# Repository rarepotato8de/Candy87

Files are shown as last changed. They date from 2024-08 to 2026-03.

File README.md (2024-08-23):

# Candy87: A universal TKL PCB 💙
The Candy87 Hotswap PCB was exclusively made for and in cooperation with [Candykeys](https://candykeys.com/) and designed to fit the Geonworks F1-8X V2 and other TKL keyboards. It supports many layout options and has awesome features!

Candy87_Top_View

## Features
- H87/H88 Compatible
- ISO and/or ANSI Support (See supported layout notes!)
- Standard and Tsangan Bottom Row
- O-Ring Cutouts
- Breakable USB-C Port (Daughterboard can be used with JST)
- Indicator LED's for Caps- and Scrolllock
- RP2040 Chip
- Broken-out GPIO Pins
- QMK/VIAL Support

## Firmware & Flashing
[QMK](https://github.com/qmk/qmk_firmware/tree/master/keyboards/candykeys/candy87) and [VIAL](https://github.com/vial-kb/vial-qmk/tree/vial/keyboards/candykeys/candy87) firmwares are available in their repositories. The compiled VIAL firmware can be found [here](https://github.com/rarepotato8de/Candy87/blob/main/candy87_vial.uf2).

To flash the PCB the first time, you just have to plug it into your computer via. USB-C or Daughterboard and then in your explorer there should appear a new drive medium called "RPI-RP2" or similar. Just drag&drop the .UF2 file onto the drive and the window should automatically close and the PCB will now be flashed and functional.
For flashing it another time, plug in the PCB and hold down the "BOOT" button on the backside of the PCB, press the "RESET" button two times and then release the "BOOT" button again. After that the "RPI-RP2" medium should appear.

## Supported layouts


> [!IMPORTANT]
> Due to hotswap sockets interfering with both ANSI and ISO support, only one of these options can be used at a time.
> Candykeys version comes with ISO by default, but by resoldering two hotswap sockets it can be ANSI. See picture below (it's resoldered to ANSI)



## Breakable USB-C Port
> [!CAUTION]
> Be careful when removing/ breaking-off the USB-C port. It should be done with caution and pliers.
> It's recommended to place the PCB on a flat surface (e.g. a table), with the USB-C port "hanging" off the side and then wiggling up and down with your pliers until it breaks off.

> [!CAUTION]
> Please do this step outside or somewhere but inside.
> You should wear glasses and a mask to prevent any health risks from the FR4 dust.

https://github.com/user-attachments/assets/5fa9985e-4570-457c-9966-bd2f55c6e134

## Open Source
This project will be open sourced in the future! Stay tuned..

## Start of this project
The project came up in the beginning of 2024 when Geonworks announced another groupbuy for his popular keyboard, the F1-8X V2. For european fellas, Candykeys wanted to offer an ISO hotswap PCB. So we talked, made plans and finally built this awesome project together!
There was a lot demand for it, people were interested and excited for it and me too! So I'm super honored to be part of this and will look forward for further projects. The Candy87 is the first project I've ever done in cooperation with a company, so I gave my best at all time. Even though we have had an issue with our first prototype, because of switch interference, the second version not only fixed this issue, but was improved even more. From the beginning it was made to be open source, because both Candykeys and I are a fan of this concept.

Big shoutout and thanks to @zitres 🍋🍋 and @candykeys 💙

## Questions?
Feel free to message me!

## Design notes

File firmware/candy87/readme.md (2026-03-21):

# Candy87

Candy87

The Candy87 Hotswap PCB is a universal TKL PCB by Candykeys.
It supports ISO Hotswap by default (ANSI possible with desolering two hotswap sockets) and many layout options. 
It was mainly made for the F1-8X V2, but fits similar keyboards as well.

* Keyboard Maintainer: [RarePotato8DE](https://github.com/rarepotato8de)
* Hardware Supported: Candy87 PCB for F1-8X V2 and similar
* Hardware Availability: [Buy on Candykeys](https://candykeys.com/product/candy87-hotswap-pcb-iso)

Make example for this keyboard (after setting up your build environment):

    make candykeys/candy87:default

Flashing example for this keyboard:

    make candykeys/candy87:default:flash

See the [build environment setup](https://docs.qmk.fm/#/getting_started_build_tools) and the [make instructions](https://docs.qmk.fm/#/getting_started_make_guide) for more information. Brand new to QMK? Start with our [Complete Newbs Guide](https://docs.qmk.fm/#/newbs).

## Bootloader

Enter the bootloader in 3 ways:

* **Bootmagic reset**: Hold down the key at (0,0) in the matrix (usually the top left key or Escape) and plug in the keyboard
* **Physical reset button**: Hold down the "BOOT" button on the back and double press "RESET". Release "BOOT" after
* **Keycode in layout**: Press the key mapped to `QK_BOOT` if it is available

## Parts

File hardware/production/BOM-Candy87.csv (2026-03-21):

Comment | Designator | Footprint | LCSC
100n | C10,C16,C2,C3,C4,C5,C6,C7,C8,C9 | C_0603_1608Metric | C14663
100nF | C17,C18,C19 | C_0402_1005Metric | C1525
1u | C12,C13 | C_0603_1608Metric | C15849
ai03_ud | J1 | JST-SR-4 | C160404
22p | C1,C11 | C_0603_1608Metric | C1653
USB_C_Receptacle_USB2.0 | J2 | USB_C_Receptacle_HRO_TYPE-C-31-M-12 | C165948
RP2040 | U1 | RP2040-QFN-56 | C2040
1k | R3,R7 | R_0603_1608Metric | C21190
470 | R8 | R_0603_1608Metric | C23179
5.1k | R4,R5 | R_0603_1608Metric | C23186
22 | R1,R2 | R_0603_1608Metric | C23345
RESET | RESET1,USB_BOOT1 | SW_SPST_TL3342 | C318884
SK6812MINI-E | LED1,LED2 | LED_6028R | C5149201
1u | MX1,MX10,MX100,MX101,MX102,MX103,MX104,MX11,MX12,MX13,MX14,MX15,MX16,MX17,MX18,MX19,MX2,MX20,MX21,MX22,MX23,MX24,MX25,MX26,MX27,MX28,MX29,MX3,MX30,MX31,MX32,MX33,MX34,MX35,MX36,MX37,MX38,MX39,MX4,MX40,MX41,MX42,MX43,MX44,MX45,MX46,MX47,MX48,MX49,MX5,MX50,MX52,MX53,MX54,MX55,MX56,MX57,MX58,MX59,MX6,MX60,MX61,MX62,MX63,MX64,MX65,MX66,MX67,MX68,MX7,MX70,MX71,MX72,MX73,MX74,MX75,MX76,MX77,MX78,MX79,MX8,MX80,MX81,MX82,MX83,MX84,MX85,MX86,MX87,MX88,MX89,MX9,MX90,MX91,MX92,MX93,MX94,MX95,MX96,MX97,MX98,MX99 | MXOnly-1U-Hotswap | C5156480
12MHz | Y1 | Crystal_SMD_3225-4Pin_3.2x2.5mm | C518158
USBLC6-2SC6 | U4 | SOT-23-6 | C558442
22u | C14,C15 | C_0603_1608Metric | C59461
AMS1117-3.3 | U2 | SOT-223-3_TabPin2 | C6186
74AHCT1G125 | U5 | SOT-23-5 | C7484
1N4148 | D1,D10,D11,D12,D13,D14,D15,D16,D17,D18,D19,D2,D20,D21,D22,D23,D24,D25,D26,D27,D28,D29,D3,D30,D31,D32,D33,D34,D35,D36,D37,D38,D39,D4,D40,D41,D42,D43,D44,D45,D46,D47,D48,D49,D5,D50,D51,D52,D53,D54,D55,D56,D57,D58,D59,D6,D60,D61,D62,D63,D64,D65,D66,D67,D68,D69,D7,D70,D71,D72,D73,D74,D75,D76,D77,D78,D79,D8,D80,D81,D82,D83,D84,D85,D86,D87,D88,D89,D9,D90,D91 | D_SOD-123 | C81598
W25Q128JVS | U3 | SOIC-8_5.23x5.23mm_P1.27mm | C97521

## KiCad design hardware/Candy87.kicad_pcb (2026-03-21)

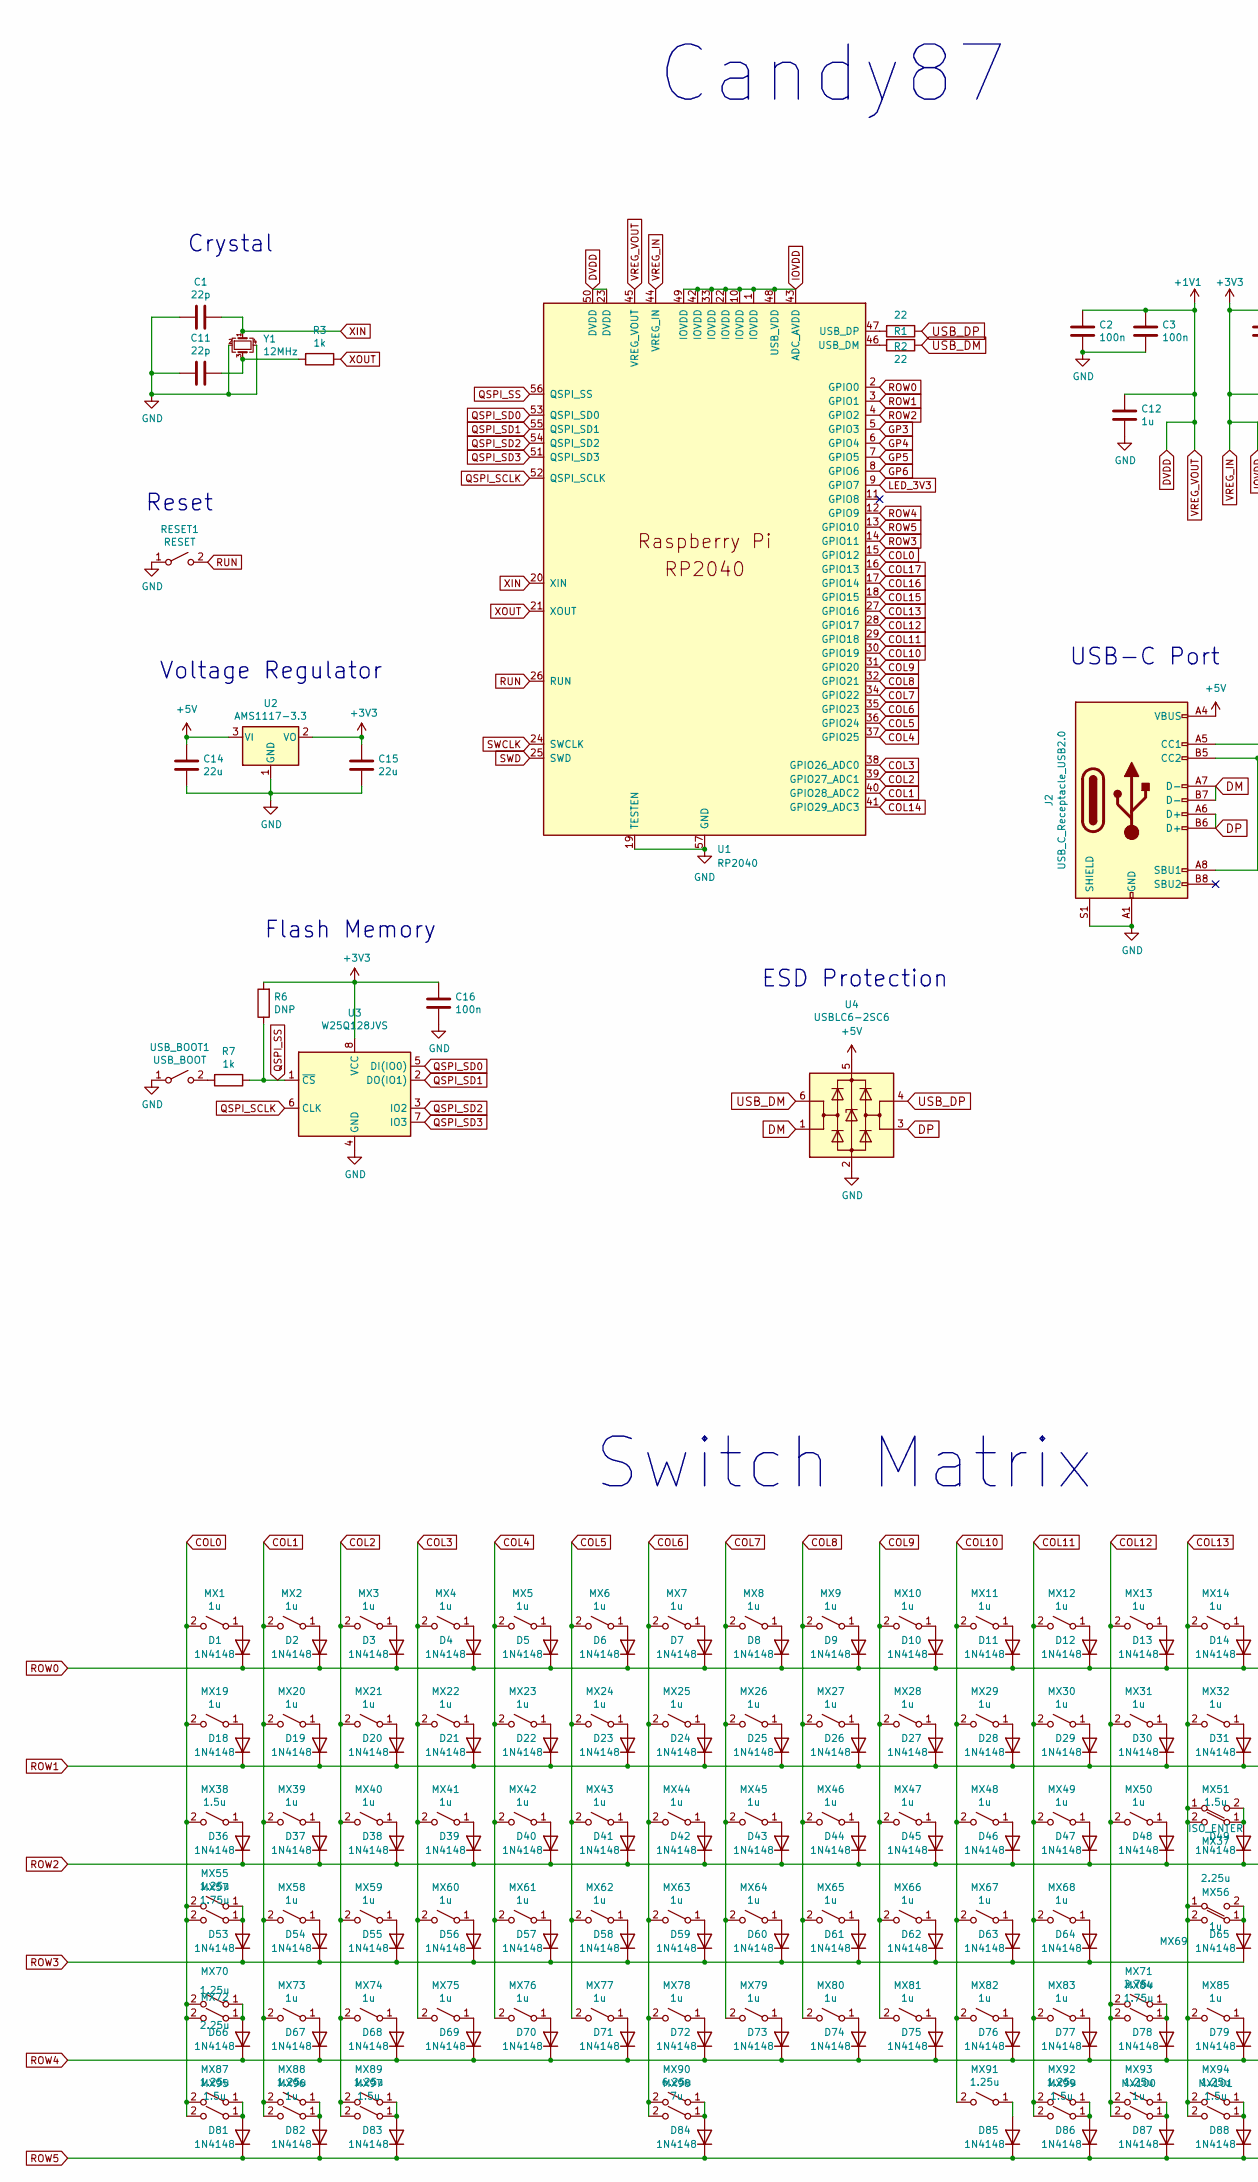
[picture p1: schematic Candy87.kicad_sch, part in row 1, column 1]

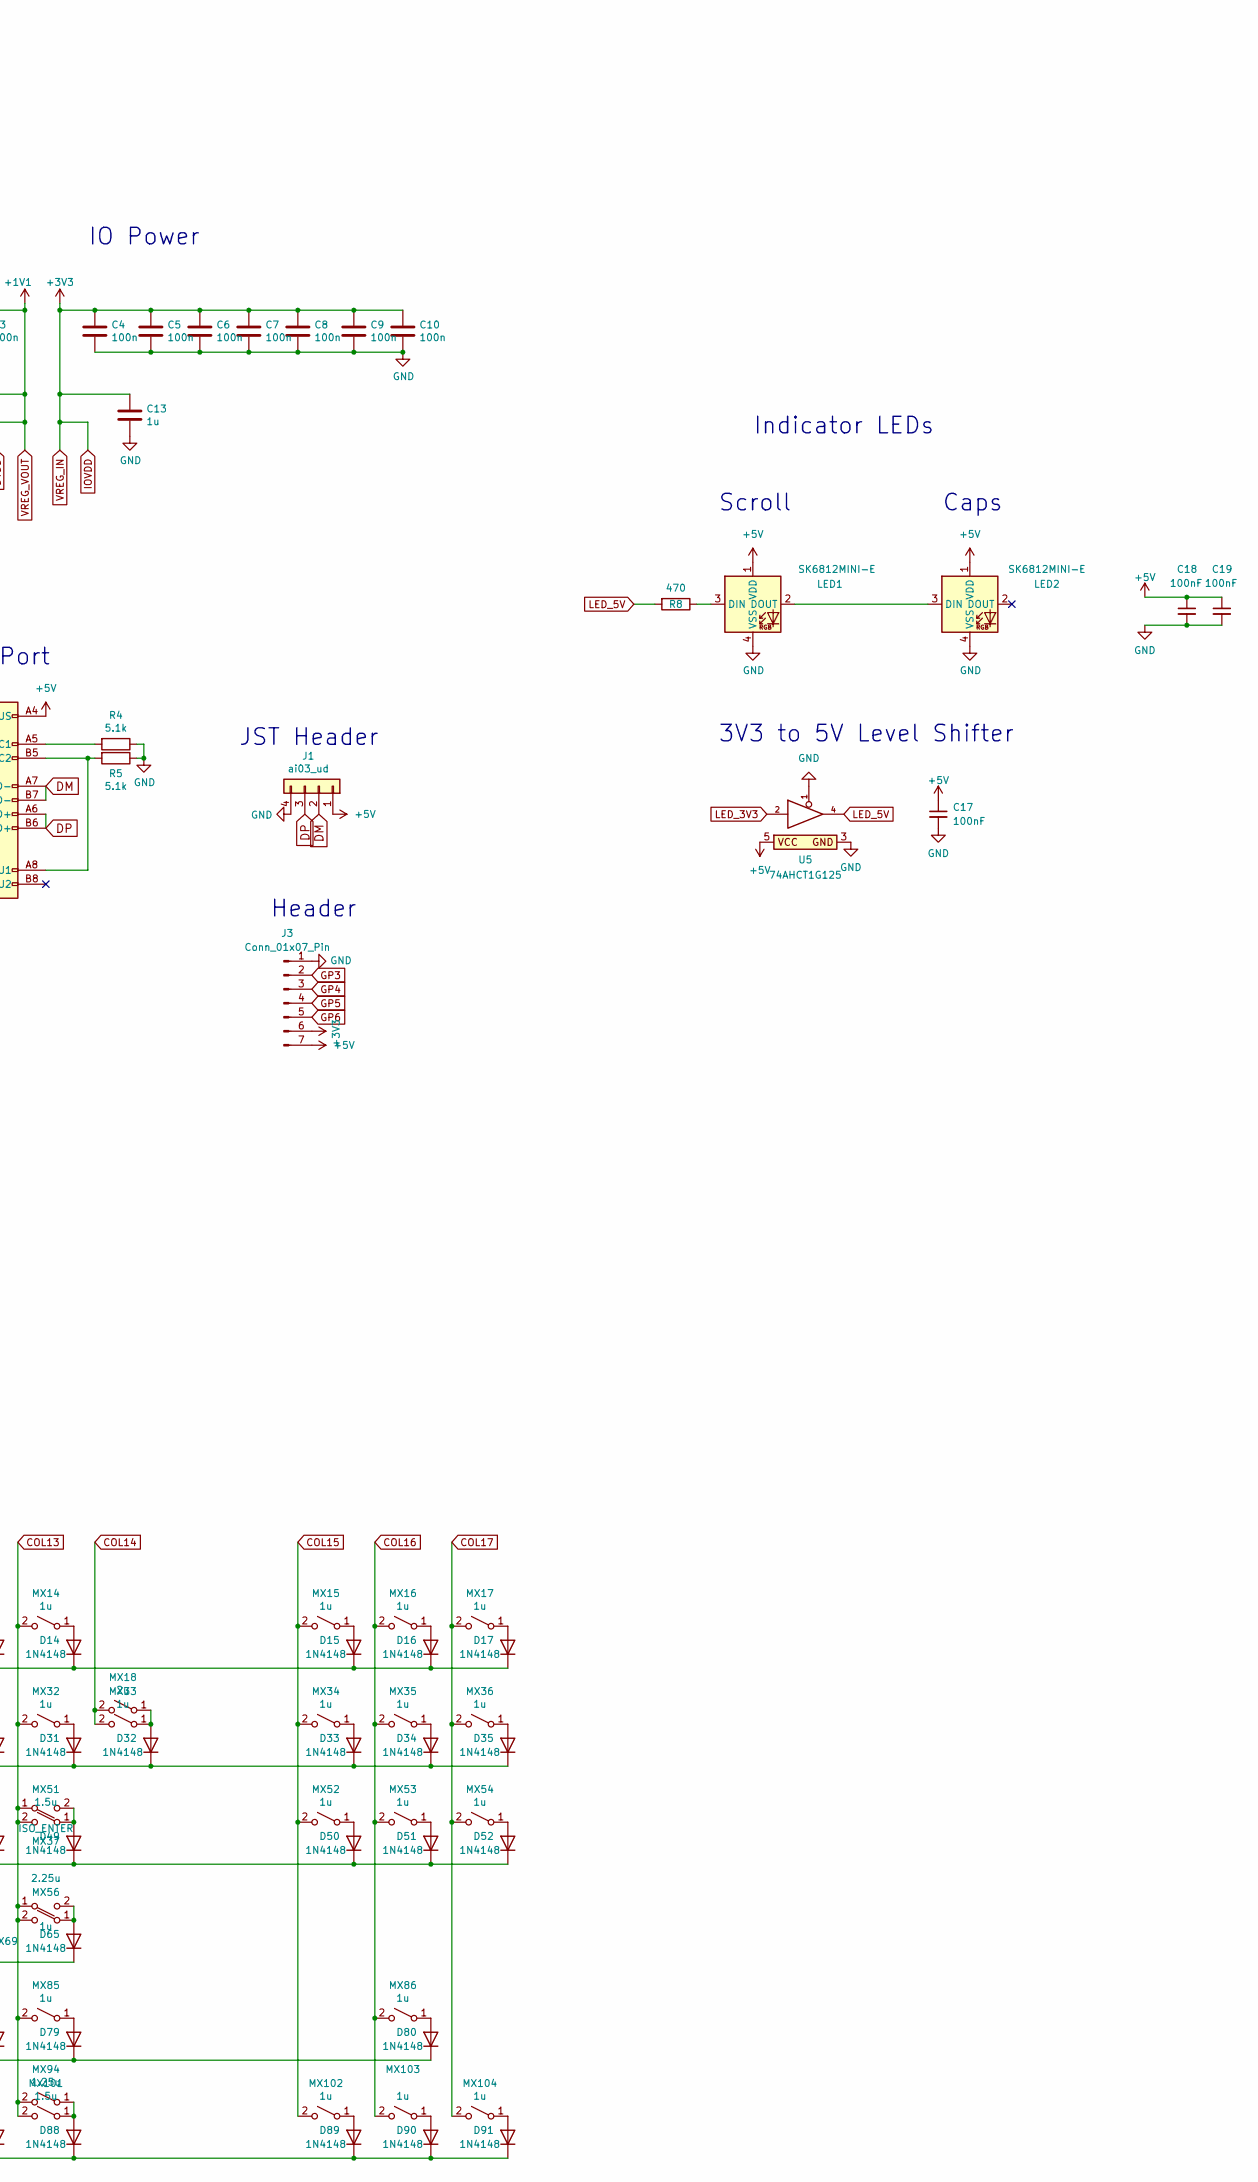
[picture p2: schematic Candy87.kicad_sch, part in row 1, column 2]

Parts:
C1, C11: 22p; C_0603_1608Metric; LCSC C1653
C2, C3, C4, C5, C6, C7, C8, C9, C10, C16: 100n; C_0603_1608Metric; LCSC C14663
C12, C13: 1u; C_0603_1608Metric; LCSC C15849
C14, C15: 22u; C_0603_1608Metric; LCSC C59461
C17, C18, C19: 100nF; C_0402_1005Metric; LCSC C1525
D1, D2, D3, D4, D5, D6, D7, D8, D9, D10, D11, D12, D13, D14, D15, D16, D17, D18, D19, D20, D21, D22, D23, D24, D25, D26, D27, D28, D29, D30, D31, D32, D33, D34, D35, D36, D37, D38, D39, D40, D41, D42, D43, D44, D45, D46, D47, D48, D49, D50, D51, D52, D53, D54, D55, D56, D57, D58, D59, D60, D61, D62, D63, D64, D65, D66, D67, D68, D69, D70, D71, D72, D73, D74, D75, D76, D77, D78, D79, D80, D81, D82, D83, D84, D85, D86, D87, D88, D89, D90, D91: 1N4148; D_SOD-123; LCSC Part # C81598
J1: ai03_ud; JST-SR-4; LCSC C160404
J2: USB_C_Receptacle_USB2.0; USB_C_Receptacle_HRO_TYPE-C-31-M-12; LCSC C165948
J3: Conn_01x07_Pin; PinSocket_1x07_P2.54mm_Vertical
LED1, LED2: SK6812MINI-E; LED_6028R; LCSC C5149201
MX1, MX2, MX3, MX4, MX5, MX6, MX7, MX8, MX9, MX10, MX11, MX12, MX13, MX14, MX15, MX16, MX17, MX19, MX20, MX21, MX22, MX23, MX24, MX25, MX26, MX27, MX28, MX29, MX30, MX31, MX32, MX33, MX34, MX35, MX36, MX39, MX40, MX41, MX42, MX43, MX44, MX45, MX46, MX47, MX48, MX49, MX50, MX52, MX53, MX54, MX56, MX58, MX59, MX60, MX61, MX62, MX63, MX64, MX65, MX66, MX67, MX68, MX73, MX74, MX75, MX76, MX77, MX78, MX79, MX80, MX81, MX82, MX83, MX85, MX86, MX96, MX100, MX102, MX103, MX104: 1u; MXOnly-1U-Hotswap; LCSC C5156480
MX18: 2u; MXOnly-2U-Hotswap; LCSC C5156480
MX37: ISO_ENTER; MXOnly-ISO-Hotswap-ReversedStabilizers; LCSC C5156480
MX38, MX95, MX97, MX99, MX101: 1.5u; MXOnly-1.5U-Hotswap; LCSC C5156480
MX51: 1.5u; MXOnly-1.5U-Hotswap
MX55, MX70, MX87, MX88, MX89, MX91, MX92, MX93, MX94: 1.25u; MXOnly-1.25U-Hotswap; LCSC C5156480
MX57, MX84: 1.75u; MXOnly-1.75U-Hotswap; LCSC C5156480
MX69: 2.25u; MXOnly-2.25U-Hotswap
MX71: 2.75u; MXOnly-2.75U-Hotswap; LCSC C5156480
MX72: 2.25u; MXOnly-2.25U-Hotswap; LCSC C5156480
MX90: 6.25u; MXOnly-6.25U-Hotswap-ReversedStabilizers; LCSC C5156480
MX98: 7u; MXOnly-7U-Hotswap; LCSC C5156480
R1, R2: 22; R_0603_1608Metric; LCSC C23345
R3, R7: 1k; R_0603_1608Metric; LCSC C21190
R4, R5: 5.1k; R_0603_1608Metric; LCSC C23186
R6: DNP; R_0603_1608Metric
R8: 470; R_0603_1608Metric; LCSC C23179
RESET1: RESET; SW_SPST_TL3342; LCSC C318884
U1: RP2040; RP2040-QFN-56; LCSC C2040
U2: AMS1117-3.3; SOT-223-3_TabPin2; LCSC C6186
U3: W25Q128JVS; SOIC-8_5.23x5.23mm_P1.27mm; LCSC C97521
U4: USBLC6-2SC6; SOT-23-6; LCSC C558442
U5: 74AHCT1G125; SOT-23-5; LCSC C7484
USB_BOOT1: USB_BOOT; SW_SPST_TL3342; LCSC C318884
Y1: 12MHz; Crystal_SMD_3225-4Pin_3.2x2.5mm; MPN Crystal MPN; LCSC C518158

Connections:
+5V: C14.1, C17.1, C18.1, C19.1, J1.1, J2.A4 (VBUS), J2.A9 (VBUS), J2.B4 (VBUS), J2.B9 (VBUS), J3.7, LED1.1 (VDD), LED2.1 (VDD), U2.3 (VI), U4.5 (VBUS), U5.5
COL0: MX1.2 (B), MX19.2 (B), MX38.2 (B), MX55.2 (B), MX57.2 (B), MX70.2 (B), MX72.2 (B), MX87.2 (B), MX95.2 (B), U1.15 (GPIO12)
COL1: MX2.2 (B), MX20.2 (B), MX39.2 (B), MX58.2 (B), MX73.2 (B), MX88.2 (B), MX96.2 (B), U1.40 (GPIO28_ADC2); also elsewhere on the board
COL2: MX3.2 (B), MX21.2 (B), MX40.2 (B), MX59.2 (B), MX74.2 (B), MX89.2 (B), MX97.2 (B), U1.39 (GPIO27_ADC1); also elsewhere on the board
COL3: MX4.2 (B), MX22.2 (B), MX41.2 (B), MX60.2 (B), MX75.2 (B), U1.38 (GPIO26_ADC0); also elsewhere on the board
COL4: MX5.2 (B), MX23.2 (B), MX42.2 (B), MX61.2 (B), MX76.2 (B), U1.37 (GPIO25); also elsewhere on the board
COL5: MX6.2 (B), MX24.2 (B), MX43.2 (B), MX62.2 (B), MX77.2 (B), U1.36 (GPIO24)
COL6: MX7.2 (B), MX25.2 (B), MX44.2 (B), MX63.2 (B), MX78.2 (B), MX90.2 (B), MX98.2 (B), U1.35 (GPIO23)
COL7: MX8.2 (B), MX26.2 (B), MX45.2 (B), MX64.2 (B), MX79.2 (B), U1.34 (GPIO22)
COL8: MX9.2 (B), MX27.2 (B), MX46.2 (B), MX65.2 (B), MX80.2 (B), U1.32 (GPIO21)
COL9: MX10.2 (B), MX28.2 (B), MX47.2 (B), MX66.2 (B), MX81.2 (B), U1.31 (GPIO20); also elsewhere on the board
COL10: MX11.2 (B), MX29.2 (B), MX48.2 (B), MX67.2 (B), MX82.2 (B), MX91.2 (B), U1.30 (GPIO19); also elsewhere on the board
COL11: MX12.2 (B), MX30.2 (B), MX49.2 (B), MX68.2 (B), MX83.2 (B), MX92.2 (B), MX99.2 (B), U1.29 (GPIO18); also elsewhere on the board
COL12: MX13.2 (B), MX31.2 (B), MX50.2 (B), MX71.2 (B), MX84.2 (B), MX93.2 (B), MX100.2 (B), U1.28 (GPIO17); also elsewhere on the board
COL13: MX14.2 (B), MX32.2 (B), MX37.1 (A), MX51.2 (B), MX56.1 (A), MX69.2 (B), MX85.2 (B), MX94.2 (B), MX101.2 (B), U1.27 (GPIO16)
COL14: MX18.2 (B), MX33.2 (B), U1.41 (GPIO29_ADC3)
COL15: MX15.2 (B), MX34.2 (B), MX52.2 (B), MX102.2 (B), U1.18 (GPIO15)
COL16: MX16.2 (B), MX35.2 (B), MX53.2 (B), MX86.2 (B), MX103.2 (B), U1.17 (GPIO14)
COL17: MX17.2 (B), MX36.2 (B), MX54.2 (B), MX104.2 (B), U1.16 (GPIO13)
DM: J1.2, J2.A7 (D-), J2.B7 (D-), U4.1 (I/O1)
DP: J1.3, J2.A6 (D+), J2.B6 (D+), U4.3 (I/O2)
DVDD: C2.1, C3.1, C12.1, U1.23 (DVDD), U1.45 (VREG_VOUT), U1.50 (DVDD)
GND: C1.2, C2.2, C3.2, C4.2, C5.2, C6.2, C7.2, C8.2, C9.2, C10.2, C11.2, C12.2, C13.2, C14.2, C15.2, C16.2, C17.2, C18.2, C19.2, J1.4, J2.A1 (GND), J2.A12 (GND), J2.B1 (GND), J2.B12 (GND), J2.S1 (SHIELD), J3.1, LED1.4 (VSS), LED2.4 (VSS), R4.1, R5.1, RESET1.1 (A), U1.19 (TESTEN), U1.57 (GND), U2.1 (GND), U3.4 (GND), U4.2 (GND), U5.1, U5.3, USB_BOOT1.1 (A), Y1.2, Y1.4
GP3: J3.2, U1.5 (GPIO3)
GP4: J3.3, U1.6 (GPIO4)
GP5: J3.4, U1.7 (GPIO5)
GP6: J3.5, U1.8 (GPIO6)
IOVDD: C4.1, C5.1, C6.1, C7.1, C8.1, C9.1, C10.1, C13.1, C15.1, C16.1, J3.6, R6.2, U1.1 (IOVDD), U1.10 (IOVDD), U1.22 (IOVDD), U1.33 (IOVDD), U1.42 (IOVDD), U1.43 (ADC_AVDD), U1.44 (VREG_IN), U1.48 (USB_VDD), U1.49 (IOVDD), U2.2 (VO), U3.8 (VCC)
LED_3V3: U1.9 (GPIO7), U5.2
LED_5V: R8.2, U5.4
unnamed: C11.1, R3.2, Y1.3
unnamed: D1.2 (A), MX1.1 (A)
unnamed 32: D2.2 (A), MX2.1 (A); also elsewhere on the board
unnamed 33: D3.2 (A), MX3.1 (A); also elsewhere on the board
unnamed 34: D4.2 (A), MX4.1 (A); also elsewhere on the board
unnamed 35: D5.2 (A), MX5.1 (A); also elsewhere on the board
unnamed: D6.2 (A), MX6.1 (A)
unnamed: D7.2 (A), MX7.1 (A)
unnamed: D8.2 (A), MX8.1 (A)
unnamed: D9.2 (A), MX9.1 (A)
unnamed 40: D10.2 (A), MX10.1 (A); also elsewhere on the board
unnamed 41: D11.2 (A), MX11.1 (A); also elsewhere on the board
unnamed 42: D12.2 (A), MX12.1 (A); also elsewhere on the board
unnamed 43: D13.2 (A), MX13.1 (A); also elsewhere on the board
unnamed: D14.2 (A), MX14.1 (A)
unnamed: D15.2 (A), MX15.1 (A)
unnamed: D16.2 (A), MX16.1 (A)
unnamed: D17.2 (A), MX17.1 (A)
unnamed: D18.2 (A), MX19.1 (A)
unnamed: D19.2 (A), MX20.1 (A)
unnamed: D20.2 (A), MX21.1 (A)
unnamed: D21.2 (A), MX22.1 (A)
unnamed: D22.2 (A), MX23.1 (A)
unnamed: D23.2 (A), MX24.1 (A)
unnamed: D24.2 (A), MX25.1 (A)
unnamed: D25.2 (A), MX26.1 (A)
unnamed: D26.2 (A), MX27.1 (A)
unnamed: D27.2 (A), MX28.1 (A)
unnamed: D28.2 (A), MX29.1 (A)
unnamed: D29.2 (A), MX30.1 (A)
unnamed: D30.2 (A), MX31.1 (A)
unnamed: D31.2 (A), MX32.1 (A)
unnamed: D32.2 (A), MX18.1 (A), MX33.1 (A)
unnamed: D33.2 (A), MX34.1 (A)
unnamed: D34.2 (A), MX35.1 (A)
unnamed: D35.2 (A), MX36.1 (A)
unnamed: D36.2 (A), MX38.1 (A)
unnamed: D37.2 (A), MX39.1 (A)
unnamed: D38.2 (A), MX40.1 (A)
unnamed: D39.2 (A), MX41.1 (A)
unnamed: D40.2 (A), MX42.1 (A)
unnamed: D41.2 (A), MX43.1 (A)
unnamed: D42.2 (A), MX44.1 (A)
unnamed: D43.2 (A), MX45.1 (A)
unnamed: D44.2 (A), MX46.1 (A)
unnamed: D45.2 (A), MX47.1 (A)
unnamed: D46.2 (A), MX48.1 (A)
unnamed: D47.2 (A), MX49.1 (A)
unnamed: D48.2 (A), MX50.1 (A)
unnamed: D49.2 (A), MX37.2 (B), MX51.1 (A)
unnamed: D50.2 (A), MX52.1 (A)
unnamed: D51.2 (A), MX53.1 (A)
unnamed: D52.2 (A), MX54.1 (A)
unnamed: D53.2 (A), MX55.1 (A), MX57.1 (A)
unnamed: D54.2 (A), MX58.1 (A)
unnamed: D55.2 (A), MX59.1 (A)
unnamed: D56.2 (A), MX60.1 (A)
unnamed: D57.2 (A), MX61.1 (A)
unnamed: D58.2 (A), MX62.1 (A)
unnamed: D59.2 (A), MX63.1 (A)
unnamed: D60.2 (A), MX64.1 (A)
unnamed: D61.2 (A), MX65.1 (A)
unnamed: D62.2 (A), MX66.1 (A)
unnamed: D63.2 (A), MX67.1 (A)
unnamed: D64.2 (A), MX68.1 (A)
unnamed: D65.2 (A), MX56.2 (B), MX69.1 (A)
unnamed: D66.2 (A), MX70.1 (A), MX72.1 (A)
unnamed: D67.2 (A), MX73.1 (A)
unnamed: D68.2 (A), MX74.1 (A)
unnamed: D69.2 (A), MX75.1 (A)
unnamed: D70.2 (A), MX76.1 (A)
unnamed: D71.2 (A), MX77.1 (A)
unnamed: D72.2 (A), MX78.1 (A)
unnamed: D73.2 (A), MX79.1 (A)
unnamed: D74.2 (A), MX80.1 (A)
unnamed: D75.2 (A), MX81.1 (A)
unnamed: D76.2 (A), MX82.1 (A)
unnamed: D77.2 (A), MX83.1 (A)
unnamed: D78.2 (A), MX71.1 (A), MX84.1 (A)
unnamed: D79.2 (A), MX85.1 (A)
unnamed: D80.2 (A), MX86.1 (A)
unnamed: D81.2 (A), MX87.1 (A), MX95.1 (A)
unnamed: D82.2 (A), MX88.1 (A), MX96.1 (A)
unnamed: D83.2 (A), MX89.1 (A), MX97.1 (A)
unnamed: D84.2 (A), MX90.1 (A), MX98.1 (A)
unnamed: D85.2 (A), MX91.1 (A)
unnamed: D86.2 (A), MX92.1 (A), MX99.1 (A)
unnamed: D87.2 (A), MX93.1 (A), MX100.1 (A)
unnamed: D88.2 (A), MX94.1 (A), MX101.1 (A)
unnamed: D89.2 (A), MX102.1 (A)
unnamed: D90.2 (A), MX103.1 (A)
unnamed: D91.2 (A), MX104.1 (A)
unnamed: J2.A5 (CC1), R4.2
unnamed: J2.A8 (SBU1), J2.B5 (CC2), R5.2
unnamed: LED1.3 (DIN), R8.1
unnamed: LED1.2 (DOUT), LED2.3 (DIN)
unnamed: R2.2, U1.46 (USB_DM)
unnamed: R1.2, U1.47 (USB_DP)
unnamed: R7.2, USB_BOOT1.2 (B)
QSPI_SCLK: U1.52 (QSPI_SCLK), U3.6 (CLK)
QSPI_SD0: U1.53 (QSPI_SD0), U3.5 (DI(IO0))
QSPI_SD1: U1.55 (QSPI_SD1), U3.2 (DO(IO1))
QSPI_SD2: U1.54 (QSPI_SD2), U3.3 (IO2)
QSPI_SD3: U1.51 (QSPI_SD3), U3.7 (IO3)
QSPI_SS: R6.1, R7.1, U1.56 (QSPI_SS), U3.1 (~CS)
ROW0: D1.1 (K), D2.1 (K), D3.1 (K), D4.1 (K), D5.1 (K), D6.1 (K), D7.1 (K), D8.1 (K), D9.1 (K), D10.1 (K), D11.1 (K), D12.1 (K), D13.1 (K), D14.1 (K), D15.1 (K), D16.1 (K), D17.1 (K), U1.2 (GPIO0)
ROW1: D18.1 (K), D19.1 (K), D20.1 (K), D21.1 (K), D22.1 (K), D23.1 (K), D24.1 (K), D25.1 (K), D26.1 (K), D27.1 (K), D28.1 (K), D29.1 (K), D30.1 (K), D31.1 (K), D32.1 (K), D33.1 (K), D34.1 (K), D35.1 (K), U1.3 (GPIO1)
ROW2: D36.1 (K), D37.1 (K), D38.1 (K), D39.1 (K), D40.1 (K), D41.1 (K), D42.1 (K), D43.1 (K), D44.1 (K), D45.1 (K), D46.1 (K), D47.1 (K), D48.1 (K), D49.1 (K), D50.1 (K), D51.1 (K), D52.1 (K), U1.4 (GPIO2)
ROW3: D53.1 (K), D54.1 (K), D55.1 (K), D56.1 (K), D57.1 (K), D58.1 (K), D59.1 (K), D60.1 (K), D61.1 (K), D62.1 (K), D63.1 (K), D64.1 (K), D65.1 (K), U1.14 (GPIO11)
ROW4: D66.1 (K), D67.1 (K), D68.1 (K), D69.1 (K), D70.1 (K), D71.1 (K), D72.1 (K), D73.1 (K), D74.1 (K), D75.1 (K), D76.1 (K), D77.1 (K), D78.1 (K), D79.1 (K), D80.1 (K), U1.12 (GPIO9)
ROW5: D81.1 (K), D82.1 (K), D83.1 (K), D84.1 (K), D85.1 (K), D86.1 (K), D87.1 (K), D88.1 (K), D89.1 (K), D90.1 (K), D91.1 (K), U1.13 (GPIO10)
RUN: RESET1.2 (B), U1.26 (RUN)
SWCLK: U1.24 (SWCLK)
SWD: U1.25 (SWD)
USB_DM: R2.1, U4.6 (I/O1)
USB_DP: R1.1, U4.4 (I/O2)
XIN: C1.1, U1.20 (XIN), Y1.1
XOUT: R3.1, U1.21 (XOUT)

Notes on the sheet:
Crystal
Header
IO Power
Caps
Flash Memory
Scroll
3V3 to 5V Level Shifter
Candy87
Voltage Regulator
Reset
JST Header
Indicator LEDs
USB-C Port
ESD Protection
Switch Matrix

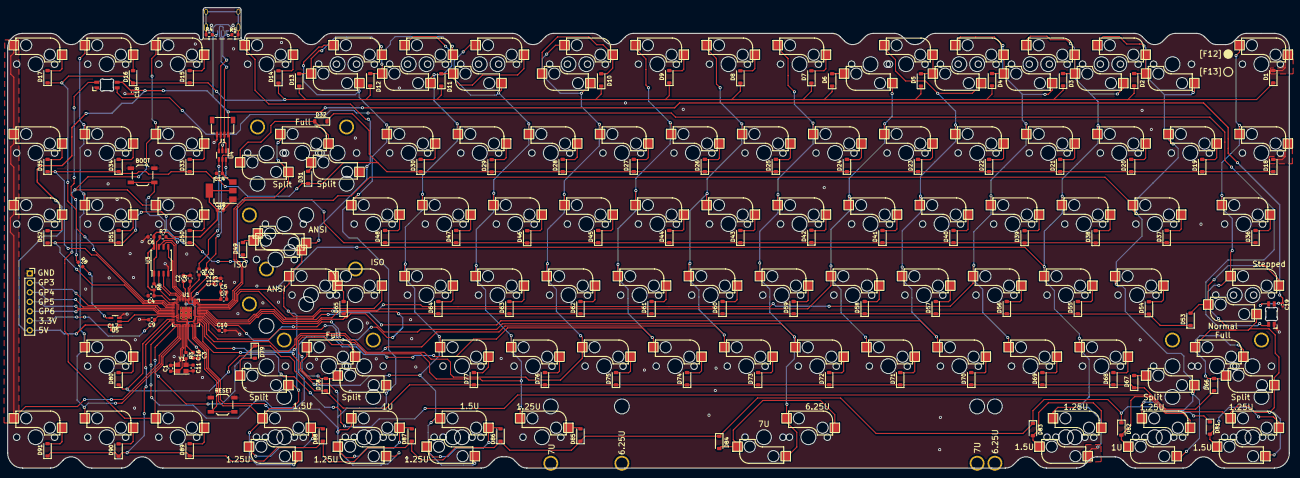
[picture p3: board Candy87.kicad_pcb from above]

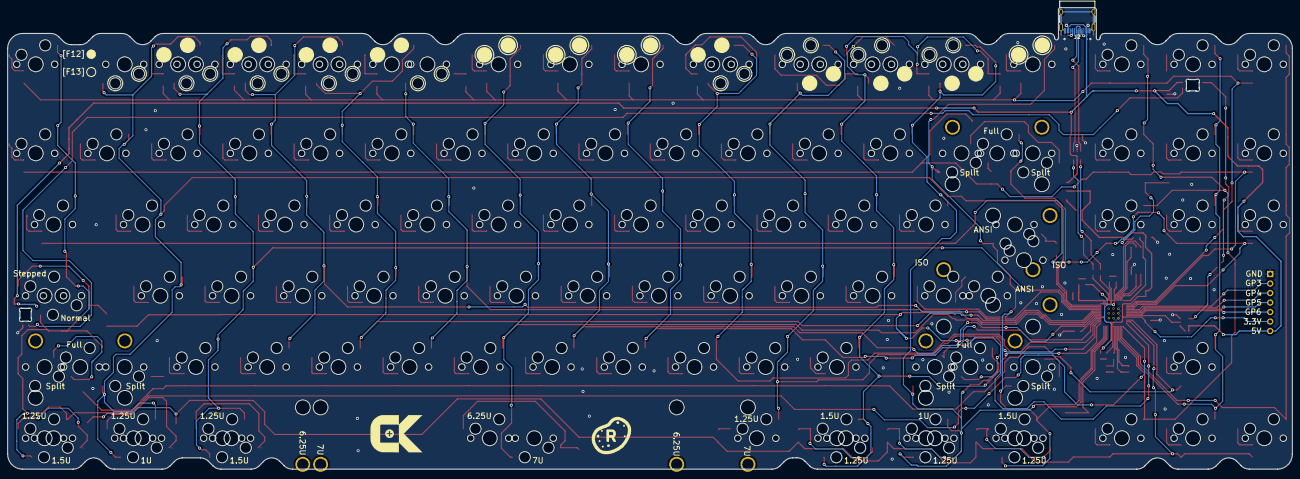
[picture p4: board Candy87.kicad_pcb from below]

Board: 2 copper layers, 343.6 x 123.4 mm, 245 parts (115 on the bottom side), 146 nets.

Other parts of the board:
MX2#2, MX3#2, MX4#2, MX5#2, MX10#2, MX11#2, MX12#2, MX13#2: 1u; MXOnly-1U-Hotswap
Ref**: Val**; ck-logo-small
Ref**#2: Val**; rarepotato

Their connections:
COL1: MX2#2.2 (B); also elsewhere on the board
COL2: MX3#2.2 (B); also elsewhere on the board
COL3: MX4#2.2 (B); also elsewhere on the board
COL4: MX5#2.2 (B); also elsewhere on the board
COL9: MX10#2.2 (B); also elsewhere on the board
COL10: MX11#2.2 (B); also elsewhere on the board
COL11: MX12#2.2 (B); also elsewhere on the board
COL12: MX13#2.2 (B); also elsewhere on the board
unnamed 32: MX2#2.1 (A); also elsewhere on the board
unnamed 33: MX3#2.1 (A); also elsewhere on the board
unnamed 34: MX4#2.1 (A); also elsewhere on the board
unnamed 35: MX5#2.1 (A); also elsewhere on the board
unnamed 40: MX10#2.1 (A); also elsewhere on the board
unnamed 41: MX11#2.1 (A); also elsewhere on the board
unnamed 42: MX12#2.1 (A); also elsewhere on the board
unnamed 43: MX13#2.1 (A); also elsewhere on the board

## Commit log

2026-03-21 OPEN SOURCE!
    Lets go, finally made it open source! Thanks to Candykeys (now called InputGear) for allowing me.
    [BOM-Candy87.csv, Candy87.kicad_pcb, Candy87.kicad_sch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]
2026-10-22 Minor changes
    Minimal changes to USB Port:
    - Removed wrong line from CC2 to A8 on USB-C
    - A tiny tiny bit bigger PCB Edge around USB Port
    Other:
    - Added/changed Logos
    New gerbers, cpl/bom stay the same (no changes)
2026-10-22 Added credits & libaries
    Libaries (footprint and symbols) added in the project
    Added credits and licenses for the used libaries
    Updated readme with credit info
